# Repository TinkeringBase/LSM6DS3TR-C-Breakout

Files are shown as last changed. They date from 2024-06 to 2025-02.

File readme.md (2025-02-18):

[한국어](https://github.com/TinkeringBase/LSM6DS3TR-C-Breakout/blob/main/readme-ko.md)
# TinkeringBase LSM6DS3TR-C IMU breakout
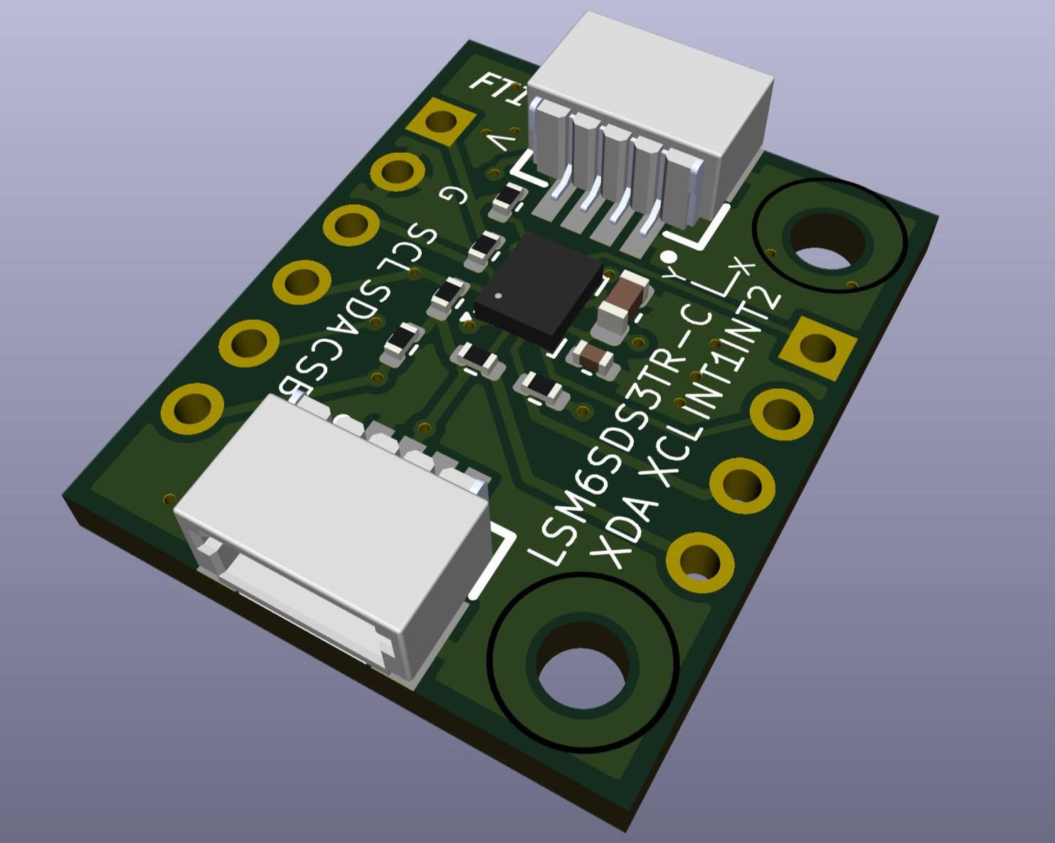
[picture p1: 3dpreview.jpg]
preview
\
Sensor breakout using ST's LSM6DS3TR-C 6DoF IMU, supports Sparkfun Qwiic system.\
While it has low price tag, it provides acceptable performance. So we recommend as entry-level IMU.

## Specification
Supply Voltage (VDD): 1.71~3.6V \
Logic Low (VIL): 0.3\*VDD max \
Logic High (VIH): 0.7\*VDD min \
Current consumption: around 0.9mA at performance mode \
for more information, see [techdata](https://www.st.com/en/mems-and-sensors/lsm6ds3tr-c.html)

## I2C address
the module uses I2C address 0b1101001 (0x6B) by default. to change it to 0b1101000 (0x6A), solder the jumper at the back side of the module.

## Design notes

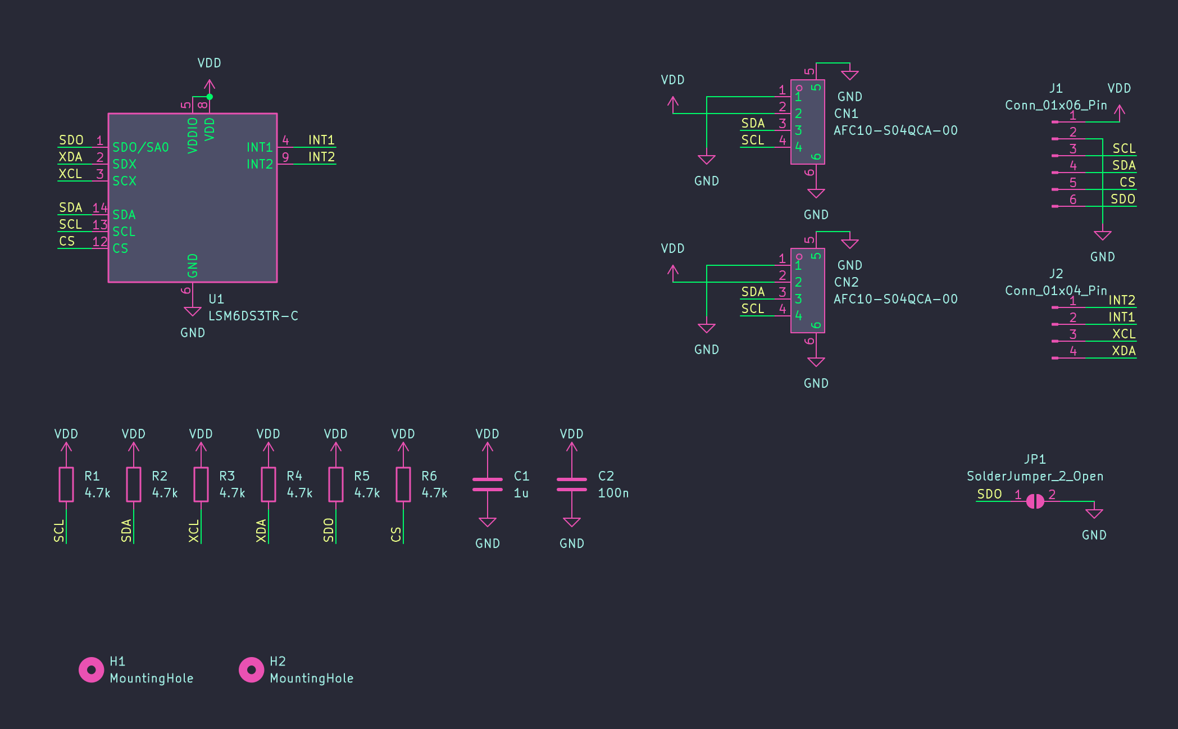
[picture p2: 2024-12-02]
schematic.png

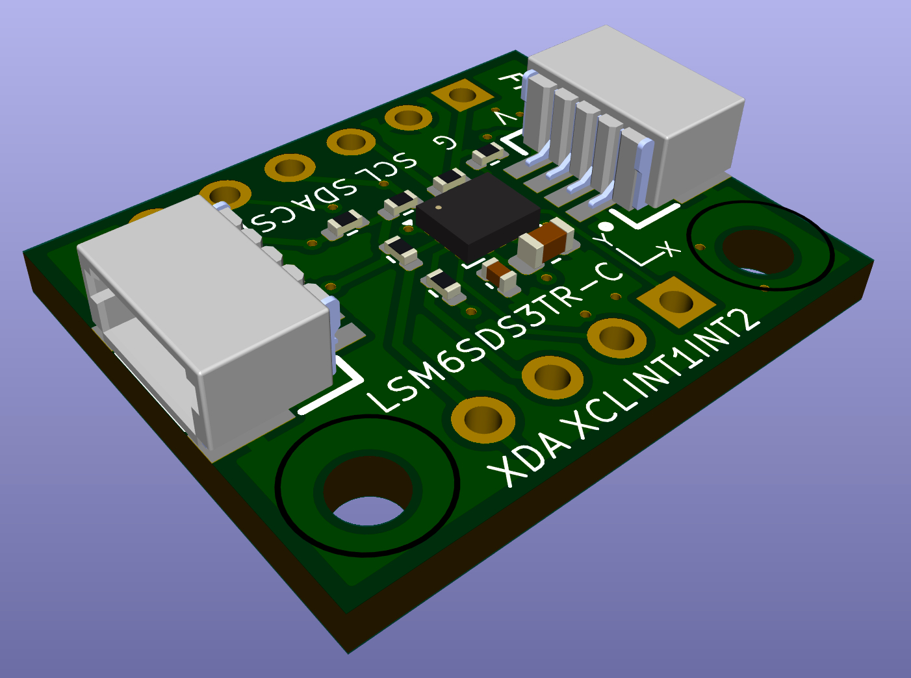
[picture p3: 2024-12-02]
3dpreview.png

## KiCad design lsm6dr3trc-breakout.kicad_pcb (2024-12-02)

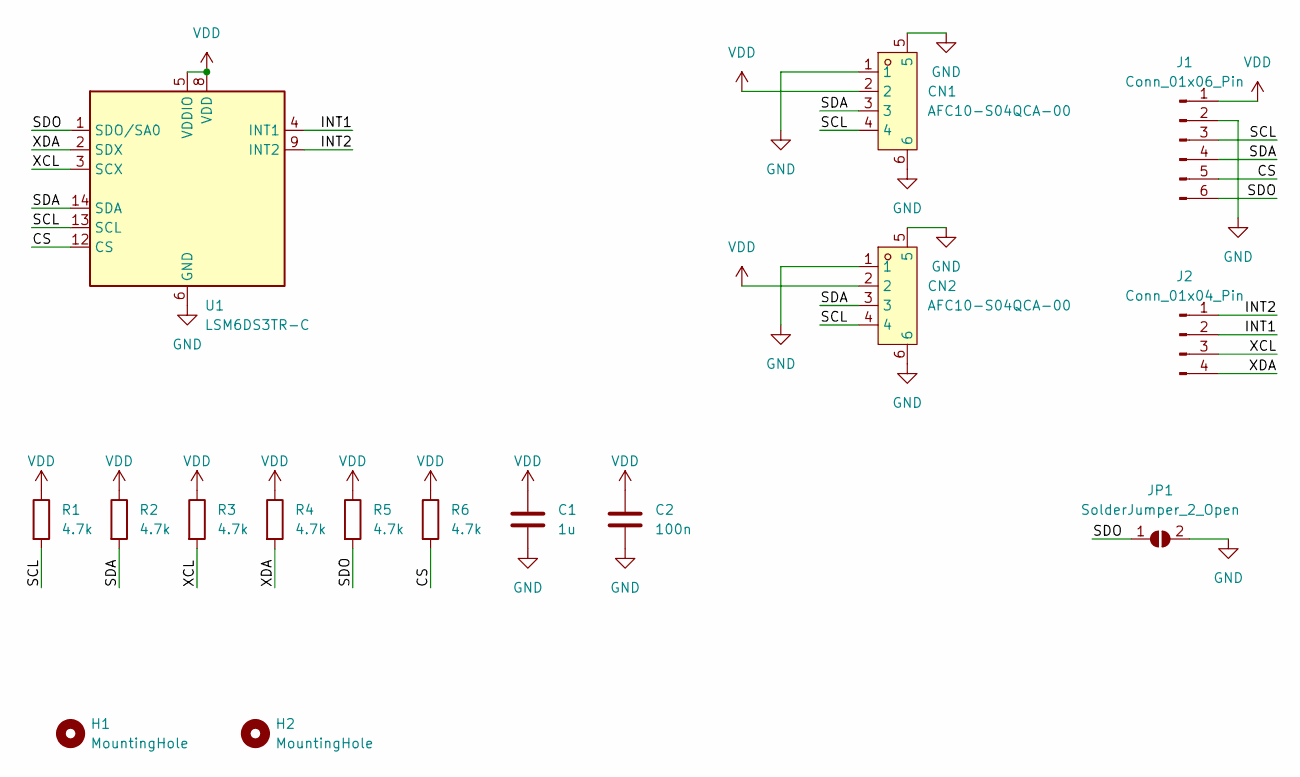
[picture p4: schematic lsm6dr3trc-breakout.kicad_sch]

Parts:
C1: 1u; C_0603_1608Metric
C2: 100n; C_0402_1005Metric
CN1, CN2: AFC10-S04QCA-00; CONN-SMD_AFC10-S04QCA-00; LCSC Part C2764183
H1, H2: MountingHole; MountingHole_2.2mm_M2
J1: Conn_01x06_Pin; PinHeader_1x06_P2.54mm_Vertical
J2: Conn_01x04_Pin; PinHeader_1x04_P2.54mm_Vertical
JP1: SolderJumper_2_Open; SolderJumper-2_P1.3mm_Open_TrianglePad1.0x1.5mm
R1, R2, R3, R4, R5, R6: 4.7k; R_0402_1005Metric
U1: LSM6DS3TR-C; LGA-14_3x2.5mm_P0.5mm_LayoutBorder3x4y

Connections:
/CS: J1.5, R6.2, U1.12 (CS)
/INT1: J2.2, U1.4 (INT1)
/INT2: J2.1, U1.9 (INT2)
/SCL: CN1.4, CN2.4, J1.3, R1.2, U1.13 (SCL)
/SDA: CN1.3, CN2.3, J1.4, R2.2, U1.14 (SDA)
/SDO: J1.6, JP1.1 (A), R5.2, U1.1 (SDO/SA0)
/XCL: J2.3, R3.2, U1.3 (SCX)
/XDA: J2.4, R4.2, U1.2 (SDX)
GND: C1.2, C2.2, CN1.1, CN1.5, CN1.6, CN2.1, CN2.5, CN2.6, J1.2, JP1.2 (B), U1.6 (GND), U1.7 (GND)
VDD: C1.1, C2.1, CN1.2, CN2.2, J1.1, R1.1, R2.1, R3.1, R4.1, R5.1, R6.1, U1.5 (VDDIO), U1.8 (VDD)

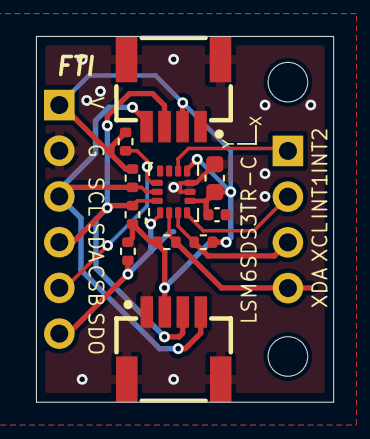
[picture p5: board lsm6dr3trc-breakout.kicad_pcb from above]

Board: 2 copper layers, 16.5 x 20.3 mm, 16 parts (1 on the bottom side), 10 nets.

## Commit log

2024-04-16 fix qwiic pinout, redo footprint
    [lsm6dr3trc-breakout.kicad_pcb, lsm6dr3trc-breakout.kicad_sch]
2024-04-16 highlight external i2c, add readme
    [lsm6dr3trc-breakout.kicad_pcb]
2024-04-23 unified IMU footprint
    [lsm6dr3trc-breakout.kicad_pcb, lsm6dr3trc-breakout.kicad_sch]
2024-05-19 fix csb resistor, beautify schematic
    [lsm6dr3trc-breakout.kicad_pcb, lsm6dr3trc-breakout.kicad_sch]
2024-11-26 use lower pullups
    [lsm6dr3trc-breakout.kicad_pcb, lsm6dr3trc-breakout.kicad_sch]
2024-12-02 make it dipable
    [lsm6dr3trc-breakout.kicad_pcb]
